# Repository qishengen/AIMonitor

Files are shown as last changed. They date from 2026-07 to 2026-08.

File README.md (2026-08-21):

# AIMonitor

用来展示 AI 状态的桌面小玩具：ESP-12F + SSD1306 128x64 OLED 动画播放器，配像素动画编辑器。支持**串口 + WiFi/TCP 双通路**控制，**浏览器 Web 配网**。

## 目录结构

```
Code/AIMonitor/            ESP8266 固件（FW 1.3.2：通信层/协议层分离 + WiFi/TCP + Web控制面板）
Code/AIMonitor/docs/       需求/设计/协议/开发摘要（DEV_CONTEXT.md 为后续开发入口）
Code/host/                 Python 上位机（protocol/aimonitor/anm_builder/pxa/ai_stream/tcp_test）
Code/host/tests/           回环自测：串口模拟 15/15 + TCP 模拟(TcpSimServer) 6/6
像素编辑器/                单文件像素动画编辑器 + PXA 分享格式（见 PXA格式.md）
scr/                       示例 GIF 素材（clawd-*.gif）
建模/                      3D 打印模型（壳体/后盖/横棍 .stl）
AIMonitor-32/              ESP32 旧原型，勿与 ESP8266 混淆
```

## 快速上手

1. **烧录**：`Code/AIMonitor` 用 Arduino IDE / arduino-cli 编译烧录（Flash Size 选 4M(FS:3M)，波特率 921600）。上电后**默认 AP+STA**（热点 `AIMonitor-xxxx` 常开），待机屏显示 WiFi 模式/名称/密码/TCP 端口。
2. **Web 控制面板**：手机/PC 连热点 `AIMonitor-xxxx`（**热点默认开放无密码**，可在配网表单「AP 热点密码」或 `ap_pass` 命令设置 ≥8 位密码）→ 浏览器开 `192.168.4.1` → 状态卡片（网络/存储/播放器/系统）+ 文件播放/删除 + 待机/主页/重启/恢复出厂/重连WiFi 按钮 + 配网表单（选 WiFi 填密码保存 → 切路由器，STA 失败 15s 自动退回热点）。门户 AP/STA 任何模式均可达。
3. **TCP 控制**：`python Code/host/tcp_test.py aimonitor.local`（或 `python tcp_test.py <设备IP>`）跑协议测试；也可连串口用原协议。
4. **编辑器**：浏览器打开 `像素编辑器/动画编辑器.html`（设备控制需 Chrome/Edge 且 localhost/https 打开，建议 `python -m http.server`）。画动画 → 上传/流式预览到设备。
5. **分享**：导出 `.pxa` 文本格式存 git，任何人可直接预览/导入。

## 协议

JSON 明文 + `\n`，帧数据体二进制或 base64 双模式。命令：ping/status/stop/list/delete/play/show/stream_*/up_*/transmit/wifi/wifi_status/**ap_pass/wifi_reconnect/home/reset/factory**。串口(921600) 与 TCP(:8088) 双通道，Web 控制面板(:80)。**命令应答只回请求来源，异步事件(进度/完成)广播**。详见 `Code/AIMonitor/docs/PROTOCOL.md` 与 `DEV_CONTEXT.md`。

## 要点速记（详见 DEV_CONTEXT.md）

- 帧数据 **LSB 位序**（字节 bit0=行最左），MSB 会左右镜像。
- GIF 编解码的 LZW 码宽时机很易错，改动需回归验证。
- 固件 IRAM 92%（WiFi 代码全进 Flash 没爆）、RAM 73%、Flash 31%，加代码需留意。
- 回包路由：命令应答回源，异步事件广播；带数据体命令同一时刻只允许一个源。

## TODO（原设想）

1. 构造协议，串口/蓝牙/WiFi 到单片机
2. 单片机做手脚：接屏显示、433 遥控，协议控制
3. 设计 skill 给 AI 装接口

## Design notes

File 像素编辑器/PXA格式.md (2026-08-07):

# PXA 像素动画格式 (v1)

面向 git 分享的**纯文本**像素画/像素动画格式：可直接在代码仓库/文本编辑器里预览，diff 友好，解析简单。

## 特性
- 纯文本、UTF-8、每帧是 ASCII 字符画 → **不装任何工具就能看**
- 自描述：尺寸/帧率/循环/名称都在头部
- 版本化（`;PXA v1`），可向后兼容扩展
- 黑白色（`#`=已绘制，`.`=空白），与 AIMonitor 设备一致；预留调色板扩展位

## 文件示例

```
;PXA v1
;W=8 H=4 F=2 FPS=12 LOOP=1
;NAME=heart
;---- FRAME 0 ----
.#....#.
##.##.##
#######
.#######.
;---- FRAME 1 ----
........
..##.##.
.#######.
.#######.
```

## 语法
| 行 | 含义 |
|---|---|
| `;PXA v1` | 魔数 + 版本（首行） |
| `;W=<宽> H=<高> F=<帧数> FPS=<帧率> LOOP=<0|1>` | 尺寸与播放参数（单行，空格分隔 K=V） |
| `;NAME=<名字>` | 可选，动画名 |
| `;---- FRAME <序号> ----` | 帧分隔符 |
| 其他行 | 像素行：**恰好 W 个字符**，`#`=已绘制(黑)，`.`=空白(白)；共 H 行/帧 |

- `;` 开头的行均为元数据/注释，解析器忽略空行。
- 像素行不足 W 字符时按缺省为 `.`；超出截断（宽容解析）。
- 位序：逐像素从左到右，字符 `#` 对应设备显示 LSB 位（bit0=行最左）。

## 与设备/工具链的关系
- `.pxa` ⇄ XBM(LSB) ⇄ `.anm`（设备二进制，固定 128×64，每帧 1024B）可互转。
- 编辑器（`动画编辑器.html`）支持**导入/导出 PXA**。
- Python 工具：`G:\AIMonitor\Code\host\pxa.py`（`to_pxa` / `parse_pxa`）。
- 上传设备前先切到 128×64(设备) 画布再导/存。

## 分享约定
- 文件名建议 `<名字>.pxa`，放入仓库任意目录即可。
- 保持每帧宽高一致、首行魔数准确，其他工具/人即可直接复用。

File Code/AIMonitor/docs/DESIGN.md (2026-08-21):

# AIMonitor 方案设计文档 (DESIGN)

> 版本: v1.0 ｜ 日期: 2026-08-07 ｜ 状态: 已评审定稿
> **v1.2 扩展（FW 1.2.0）**：架构上新增 `net`（WiFi + TCP Server :8088 + `/wifi.cfg`）与 `webcfg`（Web 配网 :80）两模块；协议状态机由 `protocol_feed()` 统一喂入串口/TCP 字节，`send()` 广播到串口 + 所有 TCP 客户端。详见 `DEV_CONTEXT.md` §13。
> **v1.3 扩展（FW 1.3.0）**：通信层/协议层分离 —— `transport`（串口+TCP+Web 统一字节收发/帧组装）与 `protocol`（命令语义）解耦；回包路由改为**命令应答回源 + 异步事件广播**；Web 门户常开并升级为控制面板（`/status`/`/cmd`）；新增 `home`/`reset`/`factory`/`wifi_reconnect` 命令。权威参考以 `PROTOCOL.md` 与 `DEV_CONTEXT.md` 为准。

## 1. 可行性评估
| 环节 | 约束 | 结论 |
|---|---|---|
| 显示刷新 | SSD1306 经 I2C 全屏刷一帧 ~26-35ms(400kHz) | 上限 ~30fps，动画足够 |
| 串口带宽 | 921600 baud ~90KB/s，单帧 1KB | 理论 ~90fps，非瓶颈 |
| 内存 | ESP-12F 堆 ~40-50KB；方案总占用 <6KB | 充裕 |
| Flash | 4MB (固件 1MB + LittleFS 3MB) | 存储量大 |

## 2. 存储容量计算
- 单帧 128x64/8 = **1024B = 1KB**
- 1 秒动画 @24fps = 24KB；@30fps = 30KB

| 项 | 计算 | 结果 |
|---|---|---|
| LittleFS 可用 | 3MB 分区扣开销 | ~2.5MB |
| 可存全屏帧 | 2.5MB / 1KB | ~2500 帧 |
| 一个动画(60帧@24fps≈2.5s) | 60KB + 8B 头 | 可存 ~40 个 |
| 连续播放上限 | 2500帧@24fps | ~100 秒 |
| 固件体积 | 动画不编译进固件 + 精简代码 | ~150-250KB |

## 3. 动画文件格式 `.anm` (LittleFS)
```
偏移   字段
0-3    "ANM0" 魔数(4B)
4      fps (1B)
5-6    frame_count 小端 (2B)
7      保留 (1B)
8..    每帧 1024B 裸 XBM，顺序拼接
```

## 4. 串口协议

### 通用约定
- 每包 = 一行 JSON 文本 (UTF-8)，以 `\n` 结尾
- 带数据体的包：JSON 头换行后紧跟 `size` 字段指定长度的原始字节
- 数据体双编码：默认二进制；`"enc":"b64"` 时数据为 JSON 内嵌 base64 字符串 `data`
- 设备对每条有效命令回 `ack`，失败回 `nack` + 错误码

### 4.1 PC -> ESP8266 命令
| 分类 | 命令 | JSON 示例 | 说明 |
|---|---|---|---|
| 控制 | ping | `{"cmd":"ping"}` | 握手，回版本/FS容量 |
| 控制 | status | `{"cmd":"status"}` | 回当前状态 |
| 控制 | stop | `{"cmd":"stop"}` | 停止播放 |
| 管理 | list | `{"cmd":"list"}` | 列动画名 |
| 管理 | delete | `{"cmd":"delete","name":"x.anm"}` | 删除动画 |
| 管理 | play | `{"cmd":"play","name":"x.anm","fps":24,"loop":1}` | 播放动画 |
| 实时 | show | `{"cmd":"show","seq":5,"size":1024}` + 1024B | 立即直显一帧，无帧率/总数，完全独立 |
| 实时 | stream_start | `{"cmd":"stream_start","fps":24,"loop":1}` | 动画流开始(total 可选) |
| 实时 | frame | `{"cmd":"frame","seq":0,"size":1024}` + 1024B | 流中一帧，设备按 fps 定时播放 |
| 实时 | stream_end | `{"cmd":"stream_end"}` | 无 total 时显式结束 |
| 写入 | up_begin | `{"cmd":"up_begin","name":"demo.anm","size":61448}` | 开始写入，回 ready |
| 写入 | up_chunk | `{"cmd":"up_chunk","off":0,"size":4096}` + 4096B | 分块写，off 支持断点续传 |
| 写入 | up_end | `{"cmd":"up_end","crc":1234567890}` | CRC32 校验落盘 |
| 写入 | transmit | `{"cmd":"transmit","name":"demo.anm","fps":24,"loop":1,"size":61440}` + 整包 | 整动画一次传入，仅保存 |

所有带数据体命令均支持 `"enc":"b64","data":"..."` 变体。

### 4.2 ESP8266 -> PC 回包
| 回包 | JSON | 含义 |
|---|---|---|
| ack | `{"resp":"ack"}` | 成功 |
| nack | `{"resp":"nack","code":n}` | 失败 (1=未知命令 2=参数错 3=文件不存在 4=CRC错 5=存储满) |
| ready | `{"resp":"ready"}` | 上传/流就绪 |
| done | `{"resp":"done"}` | 上传完成/流结束 |
| progress | `{"resp":"progress","seq":30,"fps":24}` | 播放进度 |
| state | `{"resp":"state","state":"play","name":"x.anm","seq":10}` | 状态查询/变更 |
| pong | `{"resp":"pong","fw":"1.3.2","proto":1,"fs_total":2981888,"fs_free":2800000}` | ping 响应 |
| list | `{"resp":"list","anims":["a.anm","b.anm"]}` | list 响应 |

## 5. 系统架构

### 5.1 ESP8266 固件
```
AIMonitor.ino    主循环: 非阻塞轮询串口 + 驱动播放器
json.h/cpp       最小单层 JSON 解析器 + base64 流式解码(4字符→3字节直写缓冲)
protocol.h/cpp   行缓冲(256B) + 命令分发表(CMD串→handler 函数指针)
player.h/cpp     播放状态机(IDLE/PLAY/SHOW/STREAM) + 双缓冲 + millis fps 定时
fs.h/cpp         LittleFS 读写 .anm / 断点续传 / CRC32
```

**内存预算**: U8g2 缓冲 1KB + 流式双缓冲 2KB + 串口环形缓冲 2KB + 行缓冲 256B + LittleFS 开销 ≈ **<6KB**

**播放器状态机**: IDLE / PLAY_ANIM(读FS) / STREAM(fps定时) / SHOW(即时) 四态

### 5.2 Python 上位机
```
protocol.py     JSON 编解码(bin/b64 双模式) + pySerial 封装 + 回包解析
aimonitor.py    高层 API: play/show/stream/transmit/upload/list/delete/status/ping
anm_builder.py  文字(Pillow)/图片/GIF/AI → .anm
ai_stream.py    AI 联动示例: 生成关键帧 → 流式播放
```

## 6. 优化与拓展要点
- 动画数据全部走 LittleFS，固件小巧
- 命令表为 CMD字符串→handler 映射，加指令只追加一行
- JSON 未知字段忽略 → 向后兼容
- base64 流式解码不整行缓存，省 RAM
- 流播放 fps 用 millis() 节流；LittleFS 逐帧顺序读(1KB <1ms)

## 7. 实施步骤
1. **协议层**: json.h/cpp + protocol.h/cpp + CRC，PC 端回环模拟自测
2. **播放器**: 状态机 + play(LittleFS 读 .anm 播放)
3. **实时显示**: show + stream_start/frame/stream_end，双缓冲边收边播
4. **写入保存**: up_begin/chunk/end + transmit + list/delete
5. **Python 工具集**: protocol → aimonitor → anm_builder → ai_stream
6. **实测**: 帧率/丢帧率/断线续传/稳定性

## 8. 验证方案
- PC 回环模拟器(虚拟串口或本地管道)跑通全指令
- 真机: transmit 60帧 → play 循环；show 即时；stream 24fps
- 断线续传: 中途中断后 up_chunk 指定 off 续传，CRC 通过
- Serial Monitor 人工校验 JSON 明文可读性

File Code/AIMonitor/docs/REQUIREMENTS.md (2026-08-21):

# AIMonitor 需求文档 (REQUIREMENTS)

> 版本: v1.0 ｜ 日期: 2026-08-07 ｜ 状态: 已评审定稿
> **v1.2 扩展（FW 1.2.0）**：新增 WiFi（AP/STA/AP+STA）、协议 TCP 通路(:8088)、浏览器 Web 配网(:80)、待机 IP 屏。硬件接线现为 SCL=5/SDA=4。非功能指标已放宽：固件目标 <=330KB（WiFi 栈入 Flash，实测 327KB/1MB），RAM 应用缓冲实测 64%（lwip/HTTP 缓冲入堆）。协议细节以 `PROTOCOL.md` 为准。

## 1. 项目概述
- **项目名**: AIMonitor
- **定位**: ESP8266 (ESP-12F) 驱动的 SSD1306 128x64 OLED 动画播放器
- **目标**: 通过串口接收上位机(Python)指令，按指令播放 LittleFS 中保存的动画，或实时显示上位机下发的帧。上位机集成 AI，可将文字/图片/AI 生成的内容转成动画下发播放。

## 2. 硬件环境
| 项 | 规格 |
|---|---|
| 主控 | ESP-12F (ESP8266EX, 4MB Flash, RAM ~80KB) |
| 显示屏 | SSD1306 128x64, I2C (SCL=2, SDA=0) |
| 驱动库 | U8g2: `U8G2_SSD1306_128X64_NONAME_F_SW_I2C` (全屏缓冲 1024B) |
| 上位机 | Python 3 + pySerial |
| 串口波特率 | 921600 (可配) |

## 3. 功能需求

### FR1 内置动画播放
- 按动画名播放 LittleFS 中已保存的 `.anm` 动画
- 指令可指定 fps(0=用文件头存储值) 与是否循环
- 播放中周期性上报进度

### FR2 实时帧显示 (show)
- 上位机发送一帧 → 设备立即显示一帧
- **无帧率、无总帧数**，节奏完全由上位机控制
- 与任何模式无关，任意时刻可发（播放中/空闲/流中均生效）

### FR3 动画流播放 (stream)
- 上位机连续发送多帧，设备**按 fps 在设备端定时播放**，多帧组合成动画
- `total` 可选：给则收满自动结束；不给则用 `stream_end` 显式结束
- 帧早到排队(暂存1-2帧,超出丢最新帧策略)、晚到延时到点再播
- 不落盘，适合 AI 现场生成的临时动画

### FR4 动画写入保存 (upload / transmit)
- `upload`: 分块写入大动画，支持**断点续传**、逐块确认、整文件 CRC32 校验落盘
- `transmit`: **一次性整动画传入 → 仅保存 LittleFS**，不自动播放
- 保存后重启仍在（LittleFS 持久化），可用 `play` 随时播放
- 同名文件覆盖 = 更新动画

### FR5 动画库管理
- `list`: 列出 LittleFS 中所有 `.anm` 文件
- `delete`: 按名删除动画
- 管理对象均为**动画文件（整动画）**

### FR6 双向状态上报
- 每条有效指令回 `ack`，失败回 `nack` + 错误码
- 握手 `ping` 返回固件/协议版本、FS 容量
- `status` 返回当前播放状态/动画名/帧进度
- 播放进度上报 `progress`

### FR7 协议易扩展
- 协议头为 **JSON 明文文本**，`\n` 分隔，UTF-8
- 帧/块数据体支持双编码：**原始二进制**（默认，省体积）或 **base64 内嵌 JSON**（纯文本调试/传输）
- 未知字段忽略，向后兼容

### FR8 Python 上位机工具集
- `protocol.py`: JSON 编解码(bin/b64 双模式) + 串口封装
- `aimonitor.py`: 高层 API (play/show/stream/transmit/upload/list/delete/status/ping)
- `anm_builder.py`: 文字/图片/AI → .anm 文件
- `ai_stream.py`: AI 联动示例

## 4. 非功能需求
- **固件体积**: 目标 <= 250KB (尽量精简，动画数据不编译进固件)
- **RAM**: 总占用 < 6KB (U8g2 缓冲 1KB + 双缓冲 2KB + 串口环形缓冲 2KB + 行缓冲 256B + LittleFS 开销)
- **帧率**: OLED I2C 全屏刷新上限 ~30fps；串口 921600 下理论 ~90fps，非瓶颈
- **可靠性**: 坏包丢包重同步、上传断线续传、CRC 校验失败不落盘

## 5. 验收标准
1. PC 端回环模拟器跑通全部 11 条指令的收发与 CRC
2. 真机 `transmit` 上传 60 帧动画后 `play` 正常循环播放
3. `show` 逐帧直显即时响应
4. `stream` 24fps 下无明显卡顿，`total` 与 `stream_end` 两种结束方式均正常
5. 上传中途断电/断线，重连后 `up_chunk` 指定 offset 续传成功，CRC 校验通过
6. `list` / `delete` / `ping` / `status` 全部正常

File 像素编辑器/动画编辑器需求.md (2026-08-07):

像素动画编辑器 - 需求规格说明书
1. 项目概述
一个单页 Web 应用，允许用户在可调节尺寸的画布上逐像素绘制，并管理多帧动画。支持导入/导出多种格式，包括图片、GIF 和 C 语言数组，并内置黑白位图压缩及位序配置功能。目标用户为嵌入式开发者和像素画创作者。

2. 运行环境
纯前端实现，单个 HTML 文件（内嵌 CSS 和 JS），无需构建工具或服务器。

支持现代浏览器：Chrome 90+、Firefox 88+、Edge 90+、Safari 14+。

响应式设计，移动端触摸支持。

3. 数据模型
3.1 帧数据结构
frames: Array<{ pixelData: number[][] }>

pixelData 为 gridSize × gridSize 的二维数组，每个元素为 24 位颜色值（0xRRGGBB）。

白色背景定义为 0xFFFFFF，黑色为 0x000000。

3.2 历史记录
每帧独立维护撤销/重做栈：historyStacks: Array<{ undoStack: Array<number[][]>, redoStack: Array<number[][]> }>。

最大栈深度：80 步。

3.3 全局状态
变量	类型	说明
gridSize	number	当前画布尺寸（宽高相等）
cellSize	number	画布显示单元格像素大小（固定 512px 总宽度）
currentFrameIdx	number	当前编辑帧索引
currentColor	number	当前画笔颜色（0xRRGGBB）
showGrid	boolean	是否显示网格
bwMode	boolean	恒为 true（黑白模式，彩色模式已移除）
zoomLevel	number	画布缩放级别 (1~5)
msbFirst	boolean	位图位序：true=MSB（高位对应左像素），false=LSB
refOpacity	number	参考图透明度 (0~1)
fps	number	动画播放帧率 (1~30)
loop	boolean	播放循环
4. UI 布局
整体采用垂直弹性布局，居中显示，最大宽度 900px。

4.1 布局顺序（自上而下）
标题栏：应用名称 + 画布尺寸下拉选择器（16×16 / 32×32 / 64×64 / 64×32 / 128×64(设备)）。

导入栏：导入图片（→帧）、导入 C 数组、设置参考图。

画笔栏（独占一行，内部元素分散对齐）：

颜色预设：黑、白（橡皮擦）。彩色模式已移除，仅黑白。

操作栏：撤销、重做、清空帧、反色、网格开关、选择工具。

画布区域：

缩放控制条（滑块 + 1:1 复位）。

可滚动容器内包含：

参考背景图层（，默认隐藏）。

像素画布（<canvas>，512×512 CSS 尺寸，内部像素渲染）。

参考图透明度控制条（导入后显示）。

帧操作按钮行（独立居中）：添加帧、复制帧、删除帧、上移帧、下移帧。

帧列表行（最大宽度 520px，居中）：

横向滚动缩略图，每个缩略图 56×56px。

当前帧高亮。

播放控制栏（最大宽度 520px，居中）：

播放/暂停按钮、FPS 滑块、循环复选框。

导出栏（居中）：

导出 PNG、JPEG、BMP、GIF 动画。

导出 C 数组（当前帧 / 全部帧，仅黑白字节位图）。

位序切换按钮（MSB / LSB）。

设备控制面板（新增）：串口连接、上传动画、发送当前帧、设备播放/停止、流式预览、状态查询、日志区。

状态栏：坐标、已绘制像素数、当前帧/总帧数、黑白模式、当前位序。

操作提示。

5. 功能需求
5.1 画布与绘制
5.1.1 像素绘制
使用鼠标左键拖拽绘制当前颜色，右键拖拽擦除（变为白色）。

拖动过程中使用 Bresenham 直线算法插值，保证快速移动时线条连续。

触摸屏支持单指绘制。

5.1.2 颜色管理
点击预设颜色块或使用取色器设置当前颜色。

橡皮擦本质是白色。

黑白模式下，非白色预设颜色自动隐藏，取色器强制为黑色。

5.1.3 网格显示
默认显示浅灰色网格线，可通过按钮切换。

5.1.4 画布缩放
通过滑块（1x~5x，步进 0.25）或 Ctrl+滚轮 调节缩放。

缩放仅影响 CSS transform，不改变像素数据。

缩放后画布容器可滚动。

5.2 帧与动画
5.2.1 帧管理
添加帧：在末尾创建空白帧。

复制帧：复制当前帧并插入其后。

删除帧：删除当前帧（至少保留 1 帧）。

移动帧：上移或下移当前帧。

点击缩略图切换当前编辑帧。

5.2.2 动画播放
循环播放：从当前帧开始，按顺序以设定 FPS 播放。

播放时可切换帧，但暂停后保持当前帧。

不循环时播放到最后一帧停止。

5.3 撤销/重做
每帧独立历史栈，深度 80。

操作（绘制、清空帧、反色）前自动保存快照。

快捷键：Ctrl+Z（撤销）、Ctrl+Y（重做）。

5.4 参考背景图
支持导入图片作为半透明参考图层，覆盖整个画布。

透明度滑块实时调节（0%~100%）。

可清除参考图。

参考图不参与任何导出或像素操作。

5.5 黑白模式
固定为黑白模式（彩色模式已移除），所有非白色绘制强制变为黑色。

颜色预设仅黑、白、橡皮擦。

影响 C 数组导入导出：支持字节级 bit 压缩。

图片导入仍接受彩色图，但导入时自动二值化。

5.6 导入
5.6.1 图片导入
支持 JPG、PNG、GIF。

静态图片：进入「导入预览」——等比缩放居中，可拖动移动、滚轮缩放，选择「填充(全局阈值)」「自适应(局部对比，按邻域均值保留内部明暗细节)」或「轮廓(边缘 Sobel)」二值化，应用后写入当前帧。

GIF 动画：内置 LZW 解码 + 逐帧合成（支持部分帧更新、透明、处置方式 0/1/2/3），等比适应缩放生成多帧，阈值二值化；播放用全局 FPS。

5.6.2 C 数组导入
格式识别：

十六进制字节数组（如 0xFF, 0x0F），根据当前位序解析（仅黑白）。

自动提取宏定义 WIDTH、HEIGHT、FRAME_COUNT，若与当前画布不符则提示用户选择是否调整画布尺寸。

导入前清除所有 #define 行，避免宏数字污染像素数据。

三维数组自动拆分为多帧。

5.7 导出
5.7.1 图片导出
PNG / JPEG (0.92 质量) / BMP (24位) 导出当前帧。

BMP 兼容标准格式，从下至上扫描行，4 字节对齐。

5.7.2 GIF 动画导出
将全部帧以当前 FPS 速度编码为 GIF89a 动画（无限循环）。

内置 GIF 编码器（全局调色板，LZW 压缩）。

5.7.3 C 数组导出
当前帧：const unsigned char bitmap[WIDTH * HEIGHT / 8] = { ... };

全部帧：const unsigned char animation[FRAME_COUNT][WIDTH * HEIGHT / 8] = { ... };

每个字节表示 8 个像素（1=黑，0=白）。

位序由 msbFirst 决定：MSB 时字节高位对应左像素，LSB 时低位对应左像素。

文件头部包含 #define WIDTH、#define HEIGHT、#define FRAME_COUNT（多帧时）。

导出为 .h 文件，可直接下载。

5.8 设备联动（AIMonitor）
通过 Web Serial API（Chrome/Edge，需 localhost/https 打开）连接 ESP8266。

内置 AIMonitor JSON 协议客户端：命令编解码（JSON 明文 + 原始二进制数据体），支持 show/frame/up_chunk 等带数据指令的 size 字段。

控制界面按钮：
- 连接/断开 + 波特率选择（默认 921600）。
- 上传动画：构造 .anm（ANM0 头 + fps + 帧数 + 每帧 1024B XBM），走 up_begin/up_chunk/up_end 分块上传，CRC32(zlib) 校验。
- 发送当前帧：show 命令即时在设备直显当前帧。
- 设备播放/停止：play / stop。
- 流式预览：stream_start/frame/stream_end，按编辑器 FPS 实时推流播放全部帧。
- 状态查询：ping/status/list，回显固件版本、FS 容量、动画列表。
- 日志区显示设备回包（ack/nack/progress 等）。

帧映射：任意画布尺寸等比缩放居中到设备 128×64；128×64 画布为 1:1 原生映射。

6. 交互详情
6.1 快捷键
快捷键	功能
Ctrl + Z	撤销
Ctrl + Y	重做
Ctrl + 滚轮	缩放画布
6.2 鼠标/触摸
左键拖拽：绘制

右键拖拽：擦除（或长按触摸）

滚轮 + Ctrl：缩放

6.3 选择/移动模式
进入：工具栏「🔲 选择」切换。

框选：左键按下开始框选，拖拽扩大选区，抬起结束（单击 = 选中 1 格）。

移动：在已选区域内左键按下并拖拽，像素实时跟随光标移动（实时预览），抬起落下。

取消选择：在选区外单击会开始新框选；右键单击可清空当前选择。

7. 技术实现细节
7.1 GIF 编解码
内嵌独立的 GIF 解码器（支持多帧、LZW 解压、透明色）和编码器（全局颜色表生成、LZW 压缩、动画控制）。

无任何外部依赖。

7.2 位图 bit 打包
导出/导入时按行遍历像素，每 8 个像素压入 1 字节。

位序控制：

MSB：byte |= (1 << (7 - bitPos))

LSB：byte |= (1 << bitPos)

最后不足 8 位的部分自动补零。

7.3 渲染性能
画布宽度固定 512px（cellSize = 512 / gridWidth），高度随画布高宽比自适应；128×64 画布为 512×256。

使用 image-rendering: pixelated 保持清晰边缘。

帧缩略图使用离屏 Canvas 绘制，实时更新。

8. 非功能性需求
可维护性：所有代码内嵌于单一 HTML，结构清晰，注释完整。

兼容性：移动端自适应，缩略图尺寸在窄屏自动缩小。

用户体验：操作有 Toast 提示，重要操作有确认对话框。

9. 文件清单
pixel-editor.html：包含完整 CSS、HTML 和 JavaScript（GIF 编解码器 + 主程序）。

版本历史

版本	日期	修改内容
1.0	2026-07-25	初始完整版
1.1	2026-07-25	增加画布缩放、参考图、布局调整、黑白模式、C 数组宏定义
1.2	2026-07-25	增加位序选项 (MSB/LSB)
1.3	2026-07-25	修复 C 数组导入宏污染 bug
1.4	2026-08-07	移除彩色模式（固定黑白）；支持 128×64 设备尺寸；新增 AIMonitor 设备控制面板（Web Serial 连接、上传动画、发送当前帧、设备播放/停止、流式预览、状态查询）
1.5	2026-08-07	新增 PXA 文本格式导入/导出（git 分享/预览，见 PXA格式.md）
1.6	2026-08-07	重构选择/移动：按下拖拽=框选(抬起结束)；选中区内拖拽=像素实时跟随移动；右键取消选择
1.7	2026-08-07	修复 GIF 编解码（导出结构/码宽/LZW 对齐、导入逐帧合成+处置方式）；静态图片导入改为等比+可缩放/移动+填充(阈值)/自适应(局部对比)/轮廓(Sobel)二值化

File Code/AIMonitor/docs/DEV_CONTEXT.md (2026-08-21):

# 开发摘要上下文 (DEV_CONTEXT)

> 供明天(下一会话)直接继续开发，无需重新沟通。版本: v1.5, 2026-08-21

## 1. 一句话总结
ESP-12F + SSD1306 128x64 OLED 串口动画播放器 + **像素动画编辑器** + **PXA 文本分享格式** + **WiFi/TCP 双通路** + **Web 控制面板**。固件 FW 1.3.2 编译通过（IRAM 92% 无爆），Python 回环 15/15 + TCP 回环 6/6。**FW 1.3.0 将通信层(transport)与协议层(protocol)分离**：transport 统一收串口/TCP/Web 字节并组装帧，protocol 只做命令语义；回包**应答回源 + 事件广播**；Web 门户常开（AP/STA/ap+sta 均可达）并升级为控制面板（`/status` 状态快照 + `/cmd` 控制 + 文件播放/删除 + 待机/主页/重启/恢复出厂/重连WiFi 按钮）。**FW 1.3.1 默认 `ap+sta`（AP 常开）+ 热点密码与 STA 解耦；1.3.2 新增 `ap_pass` 命令（设置/清除 AP 热点密码，串口/TCP/Web 三通道统一）。** 剩真机验证（含 TCP/Web 配网/控制面板）。

## 2. 已确定的关键决策
- 主控: **ESP-12F** (ESP8266EX, 4MB Flash)
- 动画存储: **LittleFS 文件系统** (.anm 文件，动画数据不进固件)
- 双向状态上报: **需要**
- 网络（FW 1.2.0 新增）: **WiFi AP/STA/AP+STA** + 协议 **TCP Server :8088** + **Web 配网 :80**（手写 HTTP），mDNS `aimonitor.local`；纯 STA 连不上 15s 自动退 `ap+sta` 保门户；配置存 `/wifi.cfg`
- 待机屏（FW 1.2.0 新增）: IDLE 状态显示 **IP/TCP 端口/客户端数**（`draw_idle_info`），替代原内置方块动画
- 协议: **JSON 明文文本 + `\n` 分隔**，UTF-8，非二进制魔数头
- JSON 解析: **自写最小单层解析器** (不用 ArduinoJson，省 15-25KB Flash)
- **分层（FW 1.3.0 新增）**: 通信层 `transport.cpp`（串口+TCP+Web 字节收发/帧组装）与协议层 `protocol.cpp`（命令语义）分离；数据命令头由 transport 回调 `on_header` 判定
- **回包路由（FW 1.3.0 新增）**: 命令应答**只回请求来源**（串口/TCP 对应客户端/Web HTTP 响应）；异步事件（progress/done）**广播**串口+所有 TCP
- **Web 门户常开（FW 1.3.0 新增）**: `net_apply()` 后 web server 自动重绑（`webcfg_poll` 用 `net_generation()` 检测），AP/STA/ap+sta 任何模式均可达；默认配置仍为 `ap`
- 帧数据体: **双模式** — 默认原始二进制；`"enc":"b64"` 时 base64 内嵌 JSON
- transmit 行为: **仅保存，不自动播放**，用 play 手动播
- stream 播放节奏: **设备端按 fps 定时**
- show 命令: **完全独立**，任意时刻可发，无帧率/无总帧数，上位机控节奏

## 3. 完整命令清单 (PC -> ESP)
```
{"cmd":"ping"}
{"cmd":"status"}
{"cmd":"stop"}
{"cmd":"list"}
{"cmd":"delete","name":"x.anm"}
{"cmd":"play","name":"x.anm","fps":24,"loop":1}
{"cmd":"show","seq":5,"size":1024}               + 1024B / 或 enc:b64
{"cmd":"stream_start","fps":24,"loop":1}          # total 可选
{"cmd":"frame","seq":0,"size":1024}               + 1024B / 或 enc:b64
{"cmd":"stream_end"}
{"cmd":"up_begin","name":"demo.anm","size":61448}
{"cmd":"up_chunk","off":0,"size":4096}            + 4096B / 或 enc:b64
{"cmd":"up_end","crc":1234567890}
{"cmd":"transmit","name":"demo.anm","fps":24,"loop":1,"size":61440} + 整包
{"cmd":"wifi","mode":"ap|sta|ap+sta","ssid":"..","pass":"..","port":8088}   # 可选字段，持久化+延迟~100ms应用
{"cmd":"ap_pass","pass":"..|''"}        # 设置/清除 AP 热点密码（≥8 位 WPA2，空=开放；FW 1.3.2）
{"cmd":"wifi_status"}
{"cmd":"wifi_reconnect"}        # 用已存配置重连（FW 1.3.0）
{"cmd":"home"}                  # 播放内置主页动画 idle_anim（FW 1.3.0）
{"cmd":"reset"}                 # 重启设备，ack 后延迟 300ms 重启（FW 1.3.0）
{"cmd":"factory"}               # 删 /wifi.cfg + 重启回默认 AP（FW 1.3.0）
```

## 4. 回包清单 (ESP -> PC)
```
{"resp":"ack"}   {"resp":"nack","code":1}   {"resp":"ready"}   {"resp":"done"}
{"resp":"progress","seq":30,"fps":24}
{"resp":"state","state":"play","name":"x.anm","seq":10}   # state: idle|play|stream|home
{"resp":"pong","fw":"1.3.0","proto":1,"ip":"192.168.4.1","fs_total":...,"fs_free":...}
{"resp":"wifi","mode":"ap+sta","ssid":"MyWiFi","ip":"192.168.1.50","port":8088,"clients":1,"sta":1}
{"resp":"list","anims":["a.anm","b.anm"]}
```
错误码: 1=未知命令 2=参数错 3=文件不存在 4=CRC错 5=存储满
> 路由（FW 1.3.0）：命令应答只回请求来源；progress/done 等异步事件广播到串口+所有 TCP。

## 5. .anm 文件格式
```
0-3 "ANM0" | 4 fps | 5-6 frame_count(LE) | 7 保留 | 8.. 每帧1024B裸XBM
```

## 6. 目标文件结构 (已完成)
```
AIMonitor.ino      主循环: transport_poll + net_poll + webcfg_poll + player_tick + protocol_tick；待机信息屏 draw_idle_info
version.h          FW_VERSION/PROTO_VERSION/SERIAL_BAUD 统一常量
transport.h/cpp    通信层(新)：串口+TCP+Web 源抽象 + 帧组装状态机(RX_LINE/RX_B64/RX_TAIL/RX_DATA) + 回源/广播 + transport_exec 供 Web 同步执行
json.h/cpp         最小JSON解析 + base64流式解码
protocol.h/cpp     协议层：命令分发 + 数据 sink(player/fs) + 新命令(reset/factory/home/wifi_reconnect) + 应答回源/事件广播；延迟重启/延迟重连(protocol_tick)
status.h/cpp       状态快照(新)：聚合 net/fs/player/system → Web /status 用
player.h/cpp       状态机(IDLE/PLAY/STREAM/HOME) + 双缓冲2KB + millis fps定时 + 待机信息屏回调(idle_info_cb) + home 内置动画
fs.h/cpp           LittleFS .anm 读写/续传/CRC32/list_array
net.h/cpp          WiFi(AP/STA/AP+STA) + TCP Server(:8088) + /wifi.cfg 配置(含 ap_ssid) + mDNS + STA失败15s退ap+sta兜底 + net_client_read/write + net_generation(web重绑)
webcfg.h/cpp       Web 门户(:80) 常开：GET / /scan /cfg /status，POST /save /cmd；控制面板页(状态卡片+文件播放/删除+功能按钮+配网表单)
--- 上位机 (G:\AIMonitor\Code\host) ---
protocol.py        JSON编解码(bin/b64) + 传输抽象(SerialTransport/TcpTransport/Link) + connect_tcp(host,port)
aimonitor.py       高层API play/show/stream/transmit/upload/list/delete/status/ping
anm_builder.py     文字(Pillow)/图片/GIF/AI -> .anm（to_xbm 为 LSB）
pxa.py             PXA 文本格式编解码 (to_pxa/parse_pxa)，与 .anm/XBM 互转
ai_stream.py       AI联动示例(占位生成器已改 LSB)
tcp_test.py        TCP 通路测试 (python tcp_test.py [host] [port] [--sim] [--upload x.anm])，--sim 回环 6/6
--- 测试 (G:\AIMonitor\Code\host\tests) ---
sim_firmware.py    固件行为模拟器 + TcpSimServer(挂本地 TCP 端口模拟固件 server) + wifi/wifi_status/home/reset/factory/wifi_reconnect 命令模拟
test_loopback.py   PC回环自测 15/15 通过 (python test_loopback.py)
--- 像素编辑器 (G:\AIMonitor\像素编辑器) ---
动画编辑器.html    单文件编辑器：黑白像素画/动画 + 设备控制 + PXA + GIF + 导入预览
动画编辑器需求.md  编辑器需求与版本历史
PXA格式.md         PXA 分享格式规格
```
注: 旧的 IMG.h / wait.h / Base.h (ESP32原型) 已删除/移至 AIMonitor-32，不复用。

## 7. 关键参数速查
- 单帧 128x64/8 = 1024B；1秒@24fps = 24KB；LittleFS 可用 ~2.5MB
- 串口 921600；**协议 TCP :8088；Web 配网 :80**；mDNS `aimonitor.local`；显示上限 ~30fps (I2C瓶颈)
- RAM 预算 <6KB；固件目标 <=250KB（已超出到 ~320KB，可后续裁剪）
- **位序（重要）**：设备显示 `u8g2.drawXBMP` 为 **LSB 位序**（字节 bit0=行最左像素）。所有帧数据生成必须用 LSB：
  - 编辑器 `frameToDeviceBytes`（上传/show/流式）
  - `anm_builder.py to_xbm`
  - 内置 `idle_anim.h`（数组生成脚本：`out[y*8+x//8] |= 1 << (x%8)`）
  - 用 MSB 会导致图像左右镜像。

## 8. 实施顺序 (进度)
1. 协议层: json.h/cpp + protocol.h/cpp + PC 回环自测 —— ✅ 完成
2. 播放器: 状态机 + play —— ✅ 完成
3. 实时: show + stream 双缓冲 —— ✅ 完成
4. 写入: upload + transmit + list/delete —— ✅ 完成
5. Python 工具集 —— ✅ 完成
6. WiFi/TCP 通路: net.h/cpp + protocol_feed/广播 + wifi 命令 + TcpTransport/tcp_test —— ✅ 完成
7. Web 配网: webcfg.h/cpp + STA 兜底 + mDNS + 待机 IP 屏 —— ✅ 完成（编译通过，剩真机验证）
8. 真机验证 —— ⏳ 待做（需要硬件在环）

## 9. 已修复的 bug（v1.1 会话）
- **transmit 双头**：上位机 payload 已含 8B .anm 头，固件 `fs_transmit_begin` 又写一次头 → 文件=16B+帧、无法播放。改为 payload 原样落盘（`fs_transmit_begin(name)` 不再写头）。loopback 增加 `parse_anm` 校验回归。
- **fs.cpp g_name 共享冲突**：upload/transmit 与 play 共用同一静态文件名，播放中途上传会串文件。拆分为 `g_up_name` / `g_anim_name`。
- **player.cpp `loop` 变量名**：与 Arduino 保留 `loop()` 冲突，编译报错。改名 `looping`。
- **串口高速丢字节（FW 1.1.0）**：渲染上屏(I2C ~26ms)或写 Flash 阻塞期间，内核 Serial 接收缓冲仅 256B+FIFO128B，1KB+ 帧数据突发会溢出丢字节 → 设备卡在 RX_DATA 永久不回包。修复：`setup()` 里 `Serial.setRxBufferSize(4096)`（必须在 begin 前）；协议环形缓冲 2048→8192；批写 64→256；新增 1s 收包超时（数据不完整即复位回 nack(2)，不再卡死）。
- **编辑器上传/流式**：上传分块 4096→2048、加 ping 握手、失败自动重试一次、nack 直接报真实错误码；流式预览先 `stop` 复位、`frame` 并发保护、progress 日志节流。
- **GIF 导出坏文件（v1.2 会话）**：图像描述符漏本地颜色表标志(写 0x00 又加多余字节)、min code size 硬编码 8、LZW 首个新码从 clear 开始、码宽增长时机错一个、位打包用有符号 `>>` 溢出。已修，PIL 实测 8×8~200×200 精确解码。
- **GIF 导入残缺（v1.2 会话）**：缺逐帧合成，部分帧/透明/处置方式动画只显示局部矩形。已加 `compositeAll()`（处置 0/1/2/3）+ LZW end 码占位，clawd 真机 gif 像素级一致。

## 10. 编译验证（已通过）
```
arduino-cli compile --fqbn esp8266:esp8266:generic:xtal=160,vt=flash,exception=disabled,\
stacksmash=disabled,ssl=all,mmu=3232,non32xfer=fast,FlashMode=dout,FlashFreq=40,eesz=4M3M,\
led=2,ip=lm2f,dbg=Disabled,lvl=None____,wipe=none,baud=921600 "G:\AIMonitor\Code\AIMonitor"
```
- 结果: EXITCODE=0（FW 1.3.2）。RAM 59276/80192(73%)；IRAM 60851/65536(92%)；Flash 330308B(31%)。
- 依赖: esp8266 core 3.1.2 + U8g2 2.36.19（已装）。
- 注意: WiFi 栈代码几乎全进 Flash（Flash +~49KB），IRAM 仅 +436B，没爆 92% 上限；RAM +~15KB（lwip/HTTP 缓冲/扫描），heap 缩水，加代码留意。
- **编译排坑**：本次曾两次 gcc 因临时文件失败（ICE segfault / `error writing to ...\.s`，磁盘充足，疑杀软）。设 `$env:TMP/TEMP` 到干净目录（如 `...\Temp\opencode\cc_tmp`）后正常。

## 11. 开启动画（内置程序化）
- 在 `AIMonitor.ino` `setup()` 中 `u8g2.begin()` 后阻塞播放约 1.5s：收缩状态圈 + "AIMonitor" 品牌字 + 底部进度条（带奔跑方块），结束后清屏进入主循环。
- 纯 u8g2 图元绘制，无文件/无帧缓冲依赖；用 `u8g2_font_6x13_tf` 字体（+~1KB Flash）。
- 期间串口仍能缓存少量命令（如 ping），主循环开始后正常处理；改动该动画只需改 `boot_animation()`。

## 12. 待机屏（IDLE 状态）
- **FW 1.2.0 起：IDLE 显示配网信息屏**（替代方块动画）。`player.cpp` 注册 `idle_info_cb`，`AIMonitor.ino` 的 `draw_idle_info()` 用 u8g2 6x13 画 4 行：标题 `AIMonitor` + `模式 名称`（`ap+sta AIMonitor-xxxx`，AP 开则热点名否则 STA ssid，`net_mode_str`/`net_ap_ssid_str`/`net_ssid_str`）+ `PASS xxx`（空=开放热点，`net_pass_str`）+ `TCP 8088 C:客户端数`。右上角呼吸点每 700ms 闪。**不显示 Web 端口。**
- **FW 1.3.1 起默认模式 `ap+sta`（AP 常开）**：`net_default_cfg` 默认 `ap+sta`，热点恒可用，STA 有 ssid 才连；**AP 热点密码独立**（1.3.2 `ap_pass` 命令可设，空=开放），待机屏 `PASS` 行显示 `ap_pass` 或 `PASS (open)`。
- 方块动画兜底：未注册 idle_info_cb 时仍用 `idle_anim.h`（64x64 帧数组，`idle_render()` 居中合成）。改动待机屏只改 `draw_idle_info()`。
- **FW 1.3.0：新增 `home` 命令播内置主页动画**（`player_play_home`，状态 ST_HOME，循环播放 idle_anim 直至 stop/show/play/stream；`show` 在 home 下先回 idle-hold）。
- 交互不变：`show` 置 `idle_hold=true` 暂停（保持所显帧），`play`/`stream` 结束或 `stop` 时 `idle_resume()` 恢复信息屏。

## 13. WiFi / TCP / Web 控制面板（FW 1.2.0 新增，1.3.0 升级）
- **net.h/cpp**：配置结构 `net_cfg_t`（mode/ssid/pass/ap_ssid/**ap_pass**/port/静态IP），存 `/wifi.cfg`（key=value 文本）。`net_setup()` 读取并 `net_apply()`：`WiFi.mode` 按 `ap|sta|ap+sta`、**AP 名用 `ap_ssid` 否则 `AIMonitor-<chipid>`（1.3.0 修复：不再误用 STA ssid 当热点名）**、STA 支持 DHCP/静态 IP；`WiFiServer(:8088)` + `net_client_write(idx,...)` 单发/`net_broadcast()` 广播（上限 2）。**默认模式 `ap+sta`（1.3.1，AP 常开）**。**AP 热点密码独立（1.3.2 新增 `ap_pass` 命令）**：1.3.1 曾固定开放（`pass` 曾复用为热点密码导致手机"验证身份失败"，已解耦）；现空=开放、≥8 位=WPA2（`WiFi.softAP(ssid, ap_pass? : NULL, 1, 0, 8)`，客户端上限 8）；`net_ap_pass_str()` 供待机屏/状态展示。**改网命令（wifi/ap_pass/wifi_reconnect）统一"先 ack 后延迟 ~100ms 应用"（`g_reapply_at`）**，保证串口/TCP/Web 各通道先收到回包。
- **通信层/协议层分离（FW 1.3.0）**：`transport.cpp` 统一收串口/TCP/Web 字节（同一 8KB ring）并组装帧，回调 `on_line/on_header/on_payload/on_done/on_timeout` 交给 `protocol.cpp`；`transport_exec()` 供 Web 同步执行命令并捕获回包。**回包路由：命令应答回源（`transport_send_line`）、异步事件广播（`transport_broadcast_line`）**。`show/frame/up_chunk/transmit` 同一时刻只允许一个源（单管线，天然限制）。
- **命令（1.3.0 新增）**：`home`（内置主页动画）、`reset`（ack 后延迟 300ms 重启）、`factory`（删 /wifi.cfg + 重启回默认 AP）、`wifi_reconnect`（重读配置延迟 100ms 重连，`protocol_tick` 执行）。`ping` 的 pong 含 `ip`。协议版本 `proto=1`，FW `1.3.0`。
- **webcfg.h/cpp**：手写 HTTP 门户 `:80`（不引 ESP8266WebServer，保 IRAM）。路由 `GET /`(控制面板) `/status`(状态快照) `/scan`(AP列表) `/cfg`(预填) `POST /save` `/cmd`。**`/cmd` 用 `protocol_web_exec`（1.3.1 修复：不经过 transport 帧状态机，独立解析分发，串口/TCP 数据包占用时不再返回 busy/失败）；`WEB_MAX_CLIENTS` 2→4（首页 4 个并行 fetch，防丢连接）**。**门户常开**：`webcfg_poll` 用 `net_generation()` 检测 `net_apply` 后重绑 server，AP/STA/ap+sta 均可达。配置页 JS 用 esprima 校验过；HTTP 解析逻辑有 Python 镜像测试（header_end/content_length/url_decode/分块/中文 SSID）。
- **STA 兜底**：纯 `sta` 15s 连不上 → 运行时自动退 `ap+sta` 保门户（不持久化）；mDNS `aimonitor.local`（STA 联网后可 `http://aimonitor.local`）。
- **待机屏**：IDLE 显示 IP/TCP 端口/客户端数（见 §12）。
- **上位机**：`protocol.py` 加 `TcpTransport`/`connect_tcp(host,port)`，`Link`/`AIMonitor` 零改动；`tcp_test.py` 真机/回环测试（`--sim` 用 `sim_firmware.TcpSimServer`，6/6）。编辑器仍走 Web Serial，未接 TCP/WebSocket（后续可选）。

## 14. 像素编辑器（G:\AIMonitor\像素编辑器\动画编辑器.html）
- 单文件纯前端，无依赖。**纯黑白**（彩色已移除），画布尺寸 16/32/64/64×32/128×64(设备)。
- 设备面板用 **Web Serial API**（Chrome/Edge，需 localhost/https 打开；file:// 下不可用）：连接→上传动画(分块+CRC)、发送当前帧、设备播放/停止、流式预览、状态/删除。
- 帧→设备 128×64 XBM：`frameToDeviceBytes`，**等比缩放居中**（任意画布尺寸），LSB 位序。
- 选择/移动：左键拖拽=框选(抬起结束)，选中区内拖拽=像素实时跟随，右键取消选择。
- 关键校验命令：
  - JS 语法/ID：`python C:\Users\90346\AppData\Local\Temp\opencode\check_js.py`（esprima）
  - 帧/CRC/.anm/PXA 逻辑：`check_logic.py` / `check_chain.py` / `check_pxa.py`
  - GIF 编码 vs PIL：`check_final.py`；解码 vs 真实 gif：`check_content.py`
- 注意：仓库里 `动画编辑器 - 副本.html` 是旧备份，别改错文件。

## 15. PXA 分享格式（git 友好）
- 纯文本，`;` 元数据行 + `#`=黑 `.`=白 像素行；`;PXA v1` 魔数、`;W= H= F= FPS= LOOP=`、`;NAME=`、`;---- FRAME N ----` 分隔。
- 任意尺寸，编辑器可导入/导出；Python 端 `host/pxa.py`；与 .anm 互转仅限 128×64。
- 规格见 `像素编辑器\PXA格式.md`。

## 16. GIF 编解码要点（容易再踩坑，改动需回归验证）
- **码宽增长时机**（最易错）：编码器用 `nextCode >= (1<<codeSize)+1`（比字典计数晚一个），与标准解码器"首个新码由第 2 码经 KwKwK 构建"对齐。改回 `>= (1<<codeSize)` 会导出坏文件。
- LZW 首个新码 = `clear+2`；位打包必须用无符号 `>>>`（有符号 `>>` 溢出）。
- 调色板补齐 2 的幂；min code size 与 LZW 一致；图像描述符 packed 含本地颜色表标志 `0x80|(bits-1)`。
- 解码端 `compositeAll()` 逐帧合成（部分帧/透明/处置 0/1/2/3），先合成再缩放。
- 回归：`check_final.py`（编码 vs PIL）、`check_content.py`（解码 vs 真实 gif）。

## 17. 导入图片设计（静态图片）
- 交互式「导入预览」：等比缩放居中 → 拖动移动 + 滚轮缩放(光标为中心) + ↔ 适应复位 → 应用写当前帧/取消。
- 二值化三种模式：
  - 填充(全局阈值)：`gray < T` 黑。
  - **自适应(局部对比)**：`gray < 局部均值 - C`（邻域约 1/6 画布），按局部明暗保留内部细节（照片/渐变适用）。
  - 轮廓(边缘 Sobel)：梯度幅值 > T 黑，出线稿。
- 空白区按白处理；GIF 导入走等比适应 + 阈值。

## 18. 下一步(推荐起点)
1. 真机验证（优先级）：
   - 串口/TCP 双通路：`tcp_test.py aimonitor.local`（或 AP 下 `tcp_test.py 192.168.4.1`）跑 ping/wifi_status/transmit/play/show/stream。
   - **Web 控制面板（1.3.0 新）**：连热点 `AIMonitor-xxxx` → `192.168.4.1` → 状态卡片(网络/存储/播放器/系统)自动刷新、文件列表播放/删除、按钮(待机/主页动画/重连WiFi/重启/恢复出厂)；配网表单保存后设备切 STA → `aimonitor.local` 或路由 IP 再验证；纯 sta 断网 15s 验证退 ap+sta。
   - 原有项：`transmit` 60帧 → `play` 循环；`show` 即时；`stream` 24fps 不卡；断线续传 + CRC。
2. 真机串口 921600，接线 SCL=5/SDA=4（当前 .ino 已配 ESP8266；AIMonitor-32 是旧 ESP32 原型，别混淆）。
3. 上传 60 帧素材：编辑器画 → 上传；或 `scr/` gif：`anm_builder.frames_from_gif` → `mon.transmit`。
4. 固件资源：IRAM 92%（WiFi 全进 Flash 没爆，再加代码小心）；RAM 73%（transport/status/webcfg/Web槽×4 新增）；Flash 31%。

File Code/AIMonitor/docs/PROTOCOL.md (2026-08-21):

# AIMonitor 串口协议完整规范 (PROTOCOL)

> 版本: v1.2 ｜ 日期: 2026-08-21 ｜ 实现: `Code/AIMonitor/protocol.cpp`（协议层）+ `Code/AIMonitor/transport.cpp`（通信层）+ `Code/host/protocol.py`（上位机端）
> v1.2 变更：通信层/协议层分层重构（transport.cpp 管字节收发，protocol.cpp 管命令语义）；回包路由改为**命令应答回源 + 异步事件广播**；新增 `home`/`reset`/`factory`/`wifi_reconnect` 命令；Web 门户升级为控制面板（`/status` `/cmd`）；FW 升至 1.3.0。
> v1.1 变更：新增 WiFi TCP 通路（:8088）、Web 配网（:80）、`wifi`/`wifi_status` 命令、`ping` 回包增加 `ip` 字段；FW 升至 1.2.0。

本文档为协议权威参考。数据来源：`protocol.cpp` 实际实现、`DESIGN.md`、`DEV_CONTEXT.md`。

---

## 1. 概述

| 项 | 值 |
|---|---|
| 传输介质 | 串口 UART（默认 921600 baud，可配）+ **TCP Server（默认 :8088）**，双通道共用同一协议状态机 |
| 编码 | UTF-8 文本，一包一行 |
| 包分隔 | `\n`（LF） |
| 数据体 | 原始二进制（默认）或 base64 内嵌（`"enc":"b64"`）双模式 |
| JSON 能力 | 单层解析，value 仅支持字符串/整数，未知字段忽略 |
| 协议版本 | `proto = 1`，固件 `fw = "1.3.2"` |
| Web 控制面板 | HTTP :80（`GET /` 面板、`/status` 快照、`/cfg`、`/scan`；`POST /save`、`/cmd`），非协议端口，见 `webcfg.cpp` |

接收端资源：行缓冲 256B、串口环形缓冲 8192B、数据批写 256B/批、收包不完整超时 1s（超时复位并回 `nack(2)`，防止卡死）。

**分层架构（FW 1.3.0）**：`transport.cpp`（通信层）统一收串口/TCP/Web 字节并组装帧，`protocol.cpp`（协议层）只做命令语义。回包路由：
- **命令应答**（ack/nack/ready/done/state/list/pong/wifi）→ **只回请求来源**（串口命令回串口、TCP 命令回对应客户端、Web 操作回 HTTP 响应体）
- **异步事件**（progress/done 播放上报）→ **广播**到串口 + 所有 TCP 客户端

---

## 2. 报文结构（三种形态）

### 2.1 普通命令（无数据体）

```
{"cmd":"ping","name":"x.anm","fps":24,"loop":1}\n
```

### 2.2 带数据体 — 原始二进制（默认，省体积）

JSON 头一行（含 `"size"` 声明长度），换行后紧跟 `size` 字节原始数据：

```
{"cmd":"show","seq":5,"size":1024}\n<1024 bytes raw XBM>
{"cmd":"up_chunk","off":0,"size":4096}\n<4096 bytes raw>
```

### 2.3 带数据体 — base64 内嵌（纯文本调试/传输）

数据以 base64 字符串放在 JSON 的 `"data"` 字段内，无需换行：

```
{"cmd":"show","seq":5,"size":1024,"enc":"b64","data":"AQID...=="}\n
```

> 固件端按 `"data":"` 标记流式切换到 base64 解码（`protocol.cpp:307`）。`enc` 字段本身并不参与判断，只要数据内嵌在 `"data"` 中即走 b64 路径。

---

## 3. PC → 设备 命令表

> 约定：**成功回包** 一列中的 `ack` 用 `{"resp":"ack"}` 表示；`state` 为 `{"resp":"state",...}`；`ready` 为 `{"resp":"ready",...}`。参数错一律回 `nack(2)`。

### 3.1 控制类

#### ping — 握手/探测

```json
{"cmd":"ping"}
```

- 参数：无
- 成功回包：`pong`（含固件版本/协议版本/FS 总容量/空闲）
- 失败回包：无

**demo**
```python
from protocol import Link, SerialTransport
import serial
mon_link = Link(SerialTransport(serial.Serial("COM5", 921600, timeout=0)))
print(mon_link.request({"cmd":"ping"}, expect=("pong",)))
# {"resp":"pong","fw":"1.3.2","proto":1,"ip":"192.168.4.1","fs_total":2981888,"fs_free":2800000}
```

---

#### status — 查询当前状态

```json
{"cmd":"status"}
```

- 参数：无
- 成功回包：`state`（state/name/seq）
- 失败回包：无

**demo**
```python
resp = mon_link.request({"cmd":"status"}, expect=("state",))
# {"resp":"state","state":"play","name":"demo.anm","seq":10}
```

---

#### stop — 停止播放

```json
{"cmd":"stop"}
```

- 参数：无
- 成功回包：`state`（固定 `state:"idle",name:"",seq:0`）
- 失败回包：无

**demo**
```python
mon_link.request({"cmd":"stop"}, expect=("state","ack"))
# {"resp":"state","state":"idle","name":"","seq":0}
```

---

#### home — 播放内置主页动画

```json
{"cmd":"home"}
```

- 参数：无
- 成功回包：`state`（`state:"home"`，seq:0）
- 失败回包：无
- 特性：播放内置 64x64 主页动画（`idle_anim.h`，循环），直到 `stop`/`show`/`play`/`stream` 打断；Web 控制面板「主页动画」按钮即发此命令

**demo**
```python
mon_link.request({"cmd":"home"}, expect=("state",))
# {"resp":"state","state":"home","name":"","seq":0}
```

---

### 3.2 管理类

#### list — 列出所有 .anm 动画

```json
{"cmd":"list"}
```

- 参数：无
- 成功回包：`list`（`anims` 数组）
- 失败回包：`nack(2)`（FS 枚举失败）

**demo**
```python
resp = mon_link.request({"cmd":"list"}, expect=("list",))
# {"resp":"list","anims":["demo.anm","boot.anm"]}
```

---

#### delete — 按名删除动画

```json
{"cmd":"delete","name":"demo.anm"}
```

- 参数：`name`（必填，文件名含 `.anm`）
- 成功回包：`ack`
- 失败回包：`nack(3)` 文件不存在；`nack(2)` 缺 name

**demo**
```python
resp = mon_link.request({"cmd":"delete","name":"demo.anm"})
# {"resp":"ack"}
```

---

#### play — 播放 LittleFS 中的动画

```json
{"cmd":"play","name":"demo.anm","fps":24,"loop":1}
```

- 参数：`name` 必填；`fps` 可选（0=用 .anm 文件头存储值）；`loop` 可选（非 0 循环）
- 成功回包：`state`（`state:"play"`，seq 从 0 开始）
- 失败回包：`nack(3)` 文件不存在；`nack(2)` 缺 name
- 其他：播放中周期上报 `progress`

**demo**
```python
mon_link.request(
    {"cmd":"play","name":"demo.anm","fps":24,"loop":1},
    expect=("state","ack"),
)
# {"resp":"state","state":"play","name":"demo.anm","seq":0}
```

---

### 3.3 实时显示类

#### show — 立即直显一帧

```json
{"cmd":"show","seq":5,"size":1024}\n<1024B 原始 XBM>
```

- 参数：`seq` 可选（帧序号）；`size` 必填且必须等于 `1024`
- 数据体：1 帧 128x64 XBM（1024B，LSB 位序）
- 成功回包：`ack`
- 失败回包：`nack(2)` size≠1024 或数据不完整
- 特性：完全独立，任意时刻可发（播放中/空闲/流中均生效），无帧率/总数，节奏由上位机控制

**demo**
```python
frame = bytes(1024)                     # 一帧全黑 XBM
mon_link.request({"cmd":"show","seq":5}, payload=frame, enc="bin")
# 等价 b64：mon_link.request({"cmd":"show","seq":5,"enc":"b64"},
#                           payload=frame, enc="b64")
# {"resp":"ack"}
```

---

#### stream_start — 动画流开始

```json
{"cmd":"stream_start","fps":24,"loop":1}
{"cmd":"stream_start","fps":24,"loop":0,"total":60}
```

- 参数：`fps` 可选（默认 24，固件夹到 1~60）；`loop` 可选（非 0 循环）；`total` 可选（给则收满自动结束，不给用 `stream_end` 显式结束）
- 成功回包：`state`（`state:"stream"`）
- 失败回包：无
- 特性：设备端按 fps 定时播放，帧早到排队（暂存 1-2 帧，超丢最新），晚到延时到点再播；不落盘

**demo**
```python
resp = mon_link.request(
    {"cmd":"stream_start","fps":24,"loop":1},
    expect=("state","ready"),
)
# {"resp":"state","state":"stream","name":"","seq":0}
```

---

#### frame — 流中发送一帧

```json
{"cmd":"frame","seq":0,"size":1024}\n<1024B 原始 XBM>
```

- 参数：`seq` 可选；`size` 必填且必须等于 `1024`
- 数据体：1 帧 XBM（1024B，LSB 位序）
- 成功回包：`ack`
- 失败回包：`nack(2)` size≠1024 或数据不完整

**demo**
```python
for i in range(60):
    frame = bytes(1024)                # 实际应替换为第 i 帧数据
    mon_link.request({"cmd":"frame","seq":i}, payload=frame)
    # {"resp":"ack"}
```

---

#### stream_end — 流显式结束

```json
{"cmd":"stream_end"}
```

- 参数：无
- 成功回包：`done`
- 失败回包：无
- 特性：仅当 stream_start 未给 `total` 时需要

**demo**
```python
resp = mon_link.request({"cmd":"stream_end"}, expect=("done","ack"))
# {"resp":"done"}
```

---

### 3.4 写入保存类

#### up_begin — 分块上传开始（断点续传）

```json
{"cmd":"up_begin","name":"demo.anm","size":61448}
```

- 参数：`name` 必填；`size` 必填，须 `>= 8` 且 `(size-8) % 1024 == 0`
- 成功回包：`ready`（含 `off` = 当前磁盘已写字节数，续传起点）
- 失败回包：`nack(2)` 参数错；`nack(5)` 存储满
- 特性：同名同尺寸保留原文件支持续传，否则重建

**demo**
```python
data = open("demo.anm","rb").read()   # 完整 .anm（含 8B 头）
resp = mon_link.request(
    {"cmd":"up_begin","name":"demo.anm","size":len(data)},
    expect=("ready",),
)
off = resp.get("off", 0)               # 断线后续传起点
# {"resp":"ready","off":0}
```

---

#### up_chunk — 分块写入数据

```json
{"cmd":"up_chunk","off":0,"size":4096}\n<4096B 原始>
```

- 参数：`off` 必填（>=0，写入偏移）；`size` 必填
- 数据体：任意字节数（<= 4096 建议）
- 成功回包：`ack`
- 失败回包：`nack(2)` 未先 up_begin、off 非法、或数据不完整
- 特性：off 支持断点续传；每块回 ack 后上位机发下一块

**demo**
```python
chunk = 4096
for off in range(off, len(data), chunk):
    piece = data[off:off+chunk]
    mon_link.request({"cmd":"up_chunk","off":off}, payload=piece)
    # {"resp":"ack"}
```

---

#### up_end — 上传结束 + CRC 校验落盘

```json
{"cmd":"up_end","crc":1234567890}
```

- 参数：`crc` 必填（整文件 CRC32，无符号 32 位）
- 成功回包：`done`
- 失败回包：`nack(4)` CRC 校验失败（自动删除坏文件，不落盘）；`nack(2)` 缺 crc 或未 up_begin
- 特性：CRC 校验通过才正式落盘

**demo**
```python
import zlib
crc = zlib.crc32(data) & 0xFFFFFFFF
resp = mon_link.request({"cmd":"up_end","crc":crc}, expect=("done",))
# {"resp":"done"}
```

---

#### transmit — 整动画一次传入，仅保存

```json
{"cmd":"transmit","name":"demo.anm","fps":24,"loop":1,"size":61440}\n<整 .anm 文件>
```

- 参数：`name` 必填；`size` 必填，须 `>= 8` 且 `(size-8) % 1024 == 0`；`fps`/`loop` 可选（存元数据，但播放用 play 命令指定或文件头 fps）
- 数据体：完整 `.anm` 文件（含 8B 头），原样落盘，不自动播放
- 成功回包：`done`
- 失败回包：`nack(2)` 参数错；`nack(5)` 存储满
- 特性：`fps`/`loop` 仅作记录，不参与播放控制

**demo**
```python
from anm_builder import build_anm
data = build_anm(frames, fps=24)       # frames: [1024B XBM,...]，LSB 位序
mon_link.request(
    {"cmd":"transmit","name":"demo.anm","fps":24,"loop":1,"size":len(data)},
    payload=data, expect=("done",),
)
# {"resp":"done"}
```

---

### 3.5 网络配置类

#### wifi — 配置/切换 WiFi 模式（持久化 + 即时生效）

```json
{"cmd":"wifi","mode":"sta","ssid":"MyWiFi","pass":"12345678"}
{"cmd":"wifi","mode":"ap+sta","port":9000}
```

- 参数：`mode`(ap|sta|ap+sta)、`ssid`、`pass`、`port`(1..65535) 均可选，未下发字段保持原配置
- 成功回包：`ack`（**先回包后应用**：应用配置会短暂断开当前 TCP 连接）
- 失败回包：`nack(2)` 参数错
- 特性：写入 LittleFS `/wifi.cfg` 持久化并即时生效；重启仍生效。`ap` 且 ssid 留空时热点名自动为 `AIMonitor-<chipid>`；STA 可配静态 IP（`/wifi.cfg` 手改 ip/gw/mask）。**AP 热点密码独立**（空=开放，≥8 位=WPA2，见 `ap_pass` 命令）；`pass` 仅用于 STA 连路由器，不作用于热点。客户端上限 8（`WiFi.softAP(...,max_connection=8)`）。**回包后延迟 ~100ms 应用**（`g_reapply_at`，串口/TCP/Web 各通道先收到 ack）。
- 同功能也可用 Web 配网完成：浏览器打开 `http://<设备IP>`（:80）

**demo**
```python
mon_link.request({"cmd":"wifi","mode":"sta","ssid":"MyWiFi","pass":"12345678"})
# {"resp":"ack"}
```

---

#### ap_pass — 设置/清除 AP 热点密码

```json
{"cmd":"ap_pass","pass":"12345678"}   # 设置（≥8 位，WPA2）
{"cmd":"ap_pass","pass":""}            # 清除（热点开放）
```

- 参数：`pass` 必填；空字符串=开放热点，≥8 位=启用 WPA2，长度 1~7 返回 `nack(2)`
- 成功回包：`ack`（先回包后延迟 ~100ms 应用）
- 失败回包：`nack(2)` 缺 pass 或长度 1~7
- 特性：持久化到 `/wifi.cfg` 并即时生效；与 STA 密码独立（STA 密码不作用于热点）；**串口/TCP/Web 三通道统一走协议分发**（Web 控制面板配网表单「AP 热点密码」字段同功能）；待机屏 `PASS` 行实时显示。

**demo**
```python
mon_link.request({"cmd":"ap_pass","pass":"12345678"})
# {"resp":"ack"}
```

---

#### wifi_status — 查询当前 WiFi 状态

```json
{"cmd":"wifi_status"}
```

- 参数：无
- 成功回包：`{"resp":"wifi","mode":"sta","ssid":"MyWiFi","ip":"192.168.1.50","port":8088,"clients":1,"sta":1}`
- 失败回包：无
- 字段：`mode` 当前模式、`ssid`（ap 模式留空=自动热点名）、`ip` 设备 IP、`port` TCP 端口、`clients` 已连接 TCP 客户端数、`sta` 是否已连上路由器

**demo**
```python
resp = mon_link.request({"cmd":"wifi_status"}, expect=("wifi",))
# {"resp":"wifi","mode":"ap+sta","ssid":"MyWiFi","ip":"192.168.1.50","port":8088,"clients":1,"sta":1}
```

---

### 3.6 设备管理类

#### wifi_reconnect — 用已存配置重新连接 WiFi

```json
{"cmd":"wifi_reconnect"}
```

- 参数：无
- 成功回包：`ack`（回包后延迟 ~100ms 再应用，保证 Web 请求方收到响应）
- 失败回包：无
- 特性：等价于重读 `/wifi.cfg` 并 `net_apply()`；Web 控制面板「重连WiFi」按钮即发此命令

**demo**
```python
mon_link.request({"cmd":"wifi_reconnect"})
# {"resp":"ack"}
```

---

#### reset — 重启设备

```json
{"cmd":"reset"}
```

- 参数：无
- 成功回包：`ack`（回包后延迟 ~300ms 再重启，保证响应发出）
- 失败回包：无

**demo**
```python
mon_link.request({"cmd":"reset"})
# {"resp":"ack"}  之后设备重启
```

---

#### factory — 恢复出厂（清配网 + 重启）

```json
{"cmd":"factory"}
```

- 参数：无
- 成功回包：`ack`（回包后延迟 ~300ms 再重启）
- 失败回包：无
- 特性：删除 `/wifi.cfg` 并重启，回到默认 AP 热点模式（`AIMonitor-<chipid>`，:80 配网门户可用）

**demo**
```python
mon_link.request({"cmd":"factory"})
# {"resp":"ack"}  之后设备重启回默认 AP
```

---

## 4. 设备 → PC 回包表

| 回包 | JSON | 含义 |
|---|---|---|
| ack | `{"resp":"ack"}` | 成功 |
| nack | `{"resp":"nack","code":n}` | 失败（见 §5） |
| ready | `{"resp":"ready","off":4096}` | 上传/流就绪，off 为续传起点 |
| done | `{"resp":"done"}` | 上传完成/流结束 |
| progress | `{"resp":"progress","seq":30,"fps":24}` | 播放进度（播放中周期上报，**广播**） |
| state | `{"resp":"state","state":"play","name":"x.anm","seq":10}` | 状态查询/变更结果（state 可为 idle/play/stream/home） |
| pong | `{"resp":"pong","fw":"1.3.2","proto":1,"ip":"192.168.4.1","fs_total":2981888,"fs_free":2800000}` | ping 响应 |
| wifi | `{"resp":"wifi","mode":"ap+sta","ssid":"MyWiFi","ip":"192.168.1.50","port":8088,"clients":1,"sta":1}` | wifi_status 响应 |
| list | `{"resp":"list","anims":["a.anm","b.anm"]}` | list 响应 |

> 回包同样是 `\n` 结尾的一行 JSON。上位机在等待某期望回包期间会**忽略** `progress`/`state` 等非期望回包（`protocol.py Link.request`）。

---

## 5. 错误码

| code | 含义 |
|---|---|
| 1 | 未知命令 |
| 2 | 参数错 / 数据不完整 |
| 3 | 文件不存在 |
| 4 | CRC 校验失败（坏文件不落盘） |
| 5 | 存储满 |

---

## 6. .anm 文件格式（LittleFS 存储）

```
偏移    字段
0-3     "ANM0" 魔数 (4B)
4       fps (1B)
5-6     frame_count 小端 (2B)
7       保留 (1B)
8..     每帧 1024B 裸 XBM，顺序拼接
```

- 128x64 单帧 = 128*64/8 = **1024B**
- 1 秒动画 @24fps = 24KB；LittleFS 可用约 2.5MB
- 帧 XBM 为 **LSB 位序**（字节 bit0 = 行最左像素），MSB 会左右镜像

---

## 7. 约束与注意事项

1. **LSB 位序**：所有帧数据（编辑器 `frameToDeviceBytes`、`anm_builder.to_xbm`、内置 `idle_anim.h`）必须是 LSB，否则镜像。
2. **JSON 单层解析**：value 只支持字符串/整数；命令参数中不要出现嵌套对象/数组（除 `list` 回包由固件端自行构造）。
3. **数据完整性**：带数据体命令若收到字节数与 `size` 不符，回 `nack(2)`；1s 无活动则复位状态机（防卡死）。
4. **show/frame 固定 1024B**：`size` 必须为 1024，否则 `nack(2)`。
5. **up_begin/transmit 尺寸约束**：`size >= 8` 且 `(size-8) % 1024 == 0`。
6. **stream 结束方式**：给 `total` 则收满自动结束；否则必须发 `stream_end`。
7. **transmit 不自动播放**：保存后需手动 `play`。
8. **上位机实现速查**：`Code/host/protocol.py`（`encode_packet`/`Link.request`）、`Code/host/aimonitor.py`（高层 API 已封装全部命令）。
9. **TCP 通路（FW 1.2.0）**：协议 TCP Server 默认 `:8088`；`protocol.py` 提供 `TcpTransport`/`connect_tcp(host, port)`，`Link`/`AIMonitor` 无需改动。**FW 1.3.0 起回包路由**：命令应答只回请求来源，异步事件（progress/done）广播到串口 + 所有 TCP 客户端。
10. **单数据流限制**：串口与 TCP 共享同一协议状态机，`show/frame/up_chunk/transmit` 带数据体命令同一时刻只允许一个源（双源并发会串包）。Web `:80` 走独立通道（`transport_exec` 同步执行），不受影响。
11. **Web 控制面板（FW 1.3.0）**：门户在 AP/STA/ap+sta 任何模式均可达；`GET /status` 返回聚合状态快照（网络/存储/播放器/系统），`POST /cmd` 接受 JSON 命令（body 即命令对象），响应体为回包 JSON。
12. **安全**：TCP 无鉴权即可删/传文件，仅限局域网玩具用途。

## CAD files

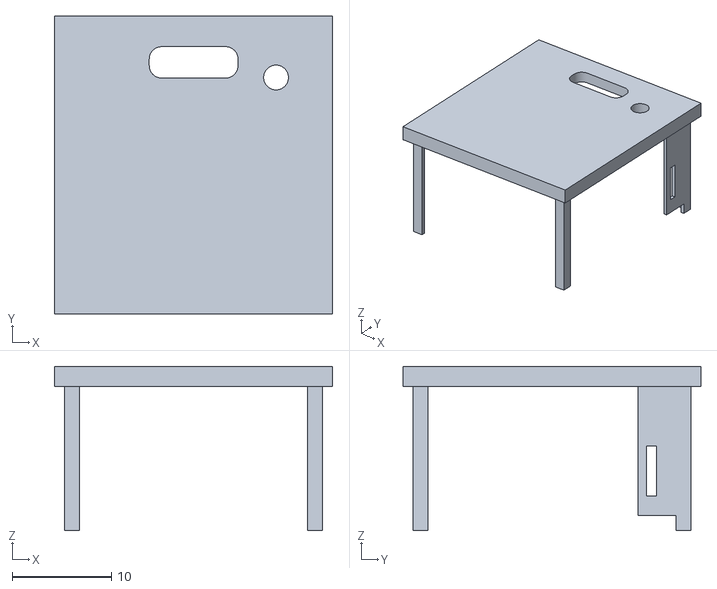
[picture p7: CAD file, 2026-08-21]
建模/后盖.stl
28.0 x 30.0 x 16.5

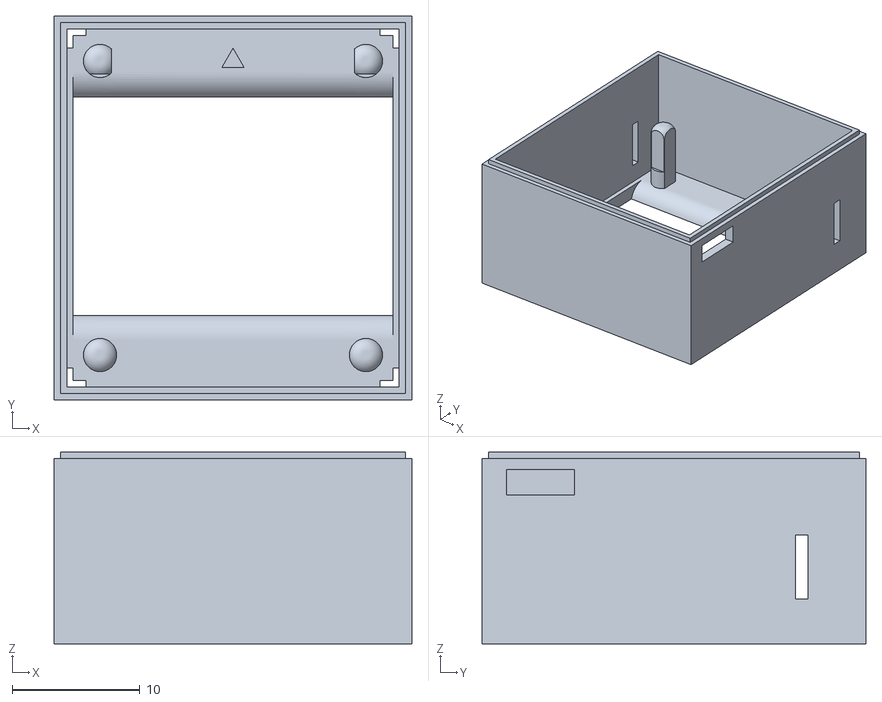
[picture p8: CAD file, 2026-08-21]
建模/壳体.stl
28.0 x 30.0 x 15.0

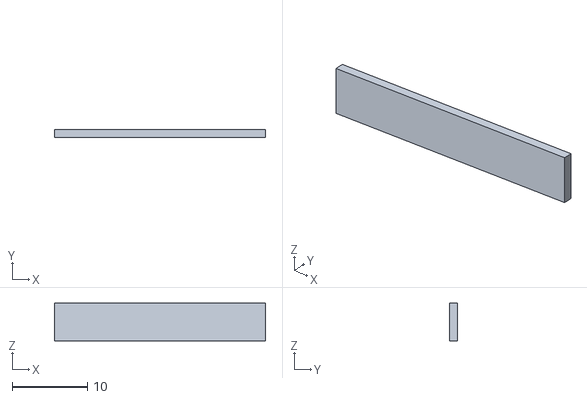
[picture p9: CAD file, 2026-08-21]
建模/横棍.stl
28.0 x 1.00 x 5.00

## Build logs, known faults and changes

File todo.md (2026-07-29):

1. 构造一个协议，串口/蓝牙/wifi to 单片机
2. 把单片机当作手脚，可以接屏幕显示，接433遥控，通过协议控制
3. 设计skill 给ai 装上接口

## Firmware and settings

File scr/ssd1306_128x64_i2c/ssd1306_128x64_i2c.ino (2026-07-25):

/**************************************************************************
 This is an example for our Monochrome OLEDs based on SSD1306 drivers

 Pick one up today in the adafruit shop!
 ------> http://www.adafruit.com/category/63_98

 This example is for a 128x64 pixel display using I2C to communicate
 3 pins are required to interface (two I2C and one reset).

 Adafruit invests time and resources providing this open
 source code, please support Adafruit and open-source
 hardware by purchasing products from Adafruit!

 Written by Limor Fried/Ladyada for Adafruit Industries,
 with contributions from the open source community.
 BSD license, check license.txt for more information
 All text above, and the splash screen below must be
 included in any redistribution.
 **************************************************************************/

#include <SPI.h>
#include <Wire.h>
#include <Adafruit_GFX.h>
#include <Adafruit_SSD1306.h>

#define SCREEN_WIDTH 128 // OLED display width, in pixels
#define SCREEN_HEIGHT 64 // OLED display height, in pixels

// Declaration for an SSD1306 display connected to I2C (SDA, SCL pins)
// The pins for I2C are defined by the Wire-library. 
// On an arduino UNO:       A4(SDA), A5(SCL)
// On an arduino MEGA 2560: 20(SDA), 21(SCL)
// On an arduino LEONARDO:   2(SDA),  3(SCL), ...
#define OLED_RESET     -1 // Reset pin # (or -1 if sharing Arduino reset pin)
#define SCREEN_ADDRESS 0x3C ///< See datasheet for Address; 0x3D for 128x64, 0x3C for 128x32
Adafruit_SSD1306 display(SCREEN_WIDTH, SCREEN_HEIGHT, &Wire, OLED_RESET);

#define NUMFLAKES     10 // Number of snowflakes in the animation example

#define LOGO_HEIGHT   16
#define LOGO_WIDTH    16
static const unsigned char PROGMEM logo_bmp[] =
{ 0b00000000, 0b11000000,
  0b00000001, 0b11000000,
  0b00000001, 0b11000000,
  0b00000011, 0b11100000,
  0b11110011, 0b11100000,
  0b11111110, 0b11111000,
  0b01111110, 0b11111111,
  0b00110011, 0b10011111,
  0b00011111, 0b11111100,
  0b00001101, 0b01110000,
  0b00011011, 0b10100000,
  0b00111111, 0b11100000,
  0b00111111, 0b11110000,
  0b01111100, 0b11110000,
  0b01110000, 0b01110000,
  0b00000000, 0b00110000 };

void setup() {
  // Wire.setPins(0,2);
  Wire.pins(0,2);
  Serial.begin(115200);

  // Wait for display
  delay(500);

  // SSD1306_SWITCHCAPVCC = generate display voltage from 3.3V internally
  if(!display.begin(SSD1306_SWITCHCAPVCC, SCREEN_ADDRESS)) {
    Serial.println(F("SSD1306 allocation failed"));
    for(;;); // Don't proceed, loop forever
  }

  // Show initial display buffer contents on the screen --
  // the library initializes this with an Adafruit splash screen.
  display.display();
  delay(2000); // Pause for 2 seconds

  // Clear the buffer
  display.clearDisplay();

  // Draw a single pixel in white
  display.drawPixel(10, 10, SSD1306_WHITE);

  // Show the display buffer on the screen. You MUST call display() after
  // drawing commands to make them visible on screen!
  display.display();
  delay(2000);
  // display.display() is NOT necessary after every single drawing command,
  // unless that's what you want...rather, you can batch up a bunch of
  // drawing operations and then update the screen all at once by calling
  // display.display(). These examples demonstrate both approaches...

  testdrawline();      // Draw many lines

  testdrawrect();      // Draw rectangles (outlines)

  testfillrect();      // Draw rectangles (filled)

  testdrawcircle();    // Draw circles (outlines)

  testfillcircle();    // Draw circles (filled)

  testdrawroundrect(); // Draw rounded rectangles (outlines)

  testfillroundrect(); // Draw rounded rectangles (filled)

  testdrawtriangle();  // Draw triangles (outlines)

  testfilltriangle();  // Draw triangles (filled)

  testdrawchar();      // Draw characters of the default font

  testdrawstyles();    // Draw 'stylized' characters

  testscrolltext();    // Draw scrolling text

  testdrawbitmap();    // Draw a small bitmap image

  // Invert and restore display, pausing in-between
  display.invertDisplay(true);
  delay(1000);
  display.invertDisplay(false);
  delay(1000);

  testanimate(logo_bmp, LOGO_WIDTH, LOGO_HEIGHT); // Animate bitmaps
}

void loop() {
}

void testdrawline() {
  int16_t i;

  display.clearDisplay(); // Clear display buffer

  for(i=0; i<display.width(); i+=4) {
    display.drawLine(0, 0, i, display.height()-1, SSD1306_WHITE);
    display.display(); // Update screen with each newly-drawn line
    delay(1);
  }
  for(i=0; i<display.height(); i+=4) {
    display.drawLine(0, 0, display.width()-1, i, SSD1306_WHITE);
    display.display();
    delay(1);
  }
  delay(250);

  display.clearDisplay();

  for(i=0; i<display.width(); i+=4) {
    display.drawLine(0, display.height()-1, i, 0, SSD1306_WHITE);
    display.display();
    delay(1);
  }
  for(i=display.height()-1; i>=0; i-=4) {
    display.drawLine(0, display.height()-1, display.width()-1, i, SSD1306_WHITE);
    display.display();
    delay(1);
  }
  delay(250);

  display.clearDisplay();

  for(i=display.width()-1; i>=0; i-=4) {
    display.drawLine(display.width()-1, display.height()-1, i, 0, SSD1306_WHITE);
    display.display();
    delay(1);
  }
  for(i=display.height()-1; i>=0; i-=4) {
    display.drawLine(display.width()-1, display.height()-1, 0, i, SSD1306_WHITE);
    display.display();
    delay(1);
  }
  delay(250);

  display.clearDisplay();

  for(i=0; i<display.height(); i+=4) {
    display.drawLine(display.width()-1, 0, 0, i, SSD1306_WHITE);
    display.display();
    delay(1);
  }
  for(i=0; i<display.width(); i+=4) {
    display.drawLine(display.width()-1, 0, i, display.height()-1, SSD1306_WHITE);
    display.display();
    delay(1);
  }

  delay(2000); // Pause for 2 seconds
}

void testdrawrect(void) {
  display.clearDisplay();

  for(int16_t i=0; i<display.height()/2; i+=2) {
    display.drawRect(i, i, display.width()-2*i, display.height()-2*i, SSD1306_WHITE);
    display.display(); // Update screen with each newly-drawn rectangle
    delay(1);
  }

  delay(2000);
}

void testfillrect(void) {
  display.clearDisplay();

  for(int16_t i=0; i<display.height()/2; i+=3) {
    // The INVERSE color is used so rectangles alternate white/black
    display.fillRect(i, i, display.width()-i*2, display.height()-i*2, SSD1306_INVERSE);
    display.display(); // Update screen with each newly-drawn rectangle
    delay(1);
  }

  delay(2000);
}

void testdrawcircle(void) {
  display.clearDisplay();

  for(int16_t i=0; i<max(display.width(),display.height())/2; i+=2) {
    display.drawCircle(display.width()/2, display.height()/2, i, SSD1306_WHITE);
    display.display();
    delay(1);
  }

  delay(2000);
}

void testfillcircle(void) {
  display.clearDisplay();

  for(int16_t i=max(display.width(),display.height())/2; i>0; i-=3) {
    // The INVERSE color is used so circles alternate white/black
    display.fillCircle(display.width() / 2, display.height() / 2, i, SSD1306_INVERSE);
    display.display(); // Update screen with each newly-drawn circle
    delay(1);
  }

  delay(2000);
}

void testdrawroundrect(void) {
  display.clearDisplay();

  for(int16_t i=0; i<display.height()/2-2; i+=2) {
    display.drawRoundRect(i, i, display.width()-2*i, display.height()-2*i,
      display.height()/4, SSD1306_WHITE);
    display.display();
    delay(1);
  }

  delay(2000);
}

void testfillroundrect(void) {
  display.clearDisplay();

  for(int16_t i=0; i<display.height()/2-2; i+=2) {
    // The INVERSE color is used so round-rects alternate white/black
    display.fillRoundRect(i, i, display.width()-2*i, display.height()-2*i,
      display.height()/4, SSD1306_INVERSE);
    display.display();
    delay(1);
  }

  delay(2000);
}

void testdrawtriangle(void) {
  display.clearDisplay();

  for(int16_t i=0; i<max(display.width(),display.height())/2; i+=5) {
    display.drawTriangle(
      display.width()/2  , display.height()/2-i,
      display.width()/2-i, display.height()/2+i,
      display.width()/2+i, display.height()/2+i, SSD1306_WHITE);
    display.display();
    delay(1);
  }

  delay(2000);
}

void testfilltriangle(void) {
  display.clearDisplay();

  for(int16_t i=max(display.width(),display.height())/2; i>0; i-=5) {
    // The INVERSE color is used so triangles alternate white/black
    display.fillTriangle(
      display.width()/2  , display.height()/2-i,
      display.width()/2-i, display.height()/2+i,
      display.width()/2+i, display.height()/2+i, SSD1306_INVERSE);
    display.display();
    delay(1);
  }

  delay(2000);
}

void testdrawchar(void) {
  display.clearDisplay();

  display.setTextSize(1);      // Normal 1:1 pixel scale
  display.setTextColor(SSD1306_WHITE); // Draw white text
  display.setCursor(0, 0);     // Start at top-left corner
  display.cp437(true);         // Use full 256 char 'Code Page 437' font

  // Not all the characters will fit on the display. This is normal.
  // Library will draw what it can and the rest will be clipped.
  for(int16_t i=0; i<256; i++) {
    if(i == '\n') display.write(' ');
    else          display.write(i);
  }

  display.display();
  delay(2000);
}

void testdrawstyles(void) {
  display.clearDisplay();

  display.setTextSize(1);             // Normal 1:1 pixel scale
  display.setTextColor(SSD1306_WHITE);        // Draw white text
  display.setCursor(0,0);             // Start at top-left corner
  display.println(F("Hello, world!"));

  display.setTextColor(SSD1306_BLACK, SSD1306_WHITE); // Draw 'inverse' text
  display.println(3.141592);

  display.setTextSize(2);             // Draw 2X-scale text
  display.setTextColor(SSD1306_WHITE);
  display.print(F("0x")); display.println(0xDEADBEEF, HEX);

  display.display();
  delay(2000);
}

void testscrolltext(void) {
  display.clearDisplay();

  display.setTextSize(2); // Draw 2X-scale text
  display.setTextColor(SSD1306_WHITE);
  display.setCursor(10, 0);
  display.println(F("scroll"));
  display.display();      // Show initial text
  delay(100);

  // Scroll in various directions, pausing in-between:
  display.startscrollright(0x00, 0x0F);
  delay(2000);
  display.stopscroll();
  delay(1000);
  display.startscrollleft(0x00, 0x0F);
  delay(2000);
  display.stopscroll();
  delay(1000);
  display.startscrolldiagright(0x00, 0x07);
  delay(2000);
  display.startscrolldiagleft(0x00, 0x07);
  delay(2000);
  display.stopscroll();
  delay(1000);
}

void testdrawbitmap(void) {
  display.clearDisplay();

  display.drawBitmap(
    (display.width()  - LOGO_WIDTH ) / 2,
    (display.height() - LOGO_HEIGHT) / 2,
    logo_bmp, LOGO_WIDTH, LOGO_HEIGHT, 1);
  display.display();
  delay(1000);
}

#define XPOS   0 // Indexes into the 'icons' array in function below
#define YPOS   1
#define DELTAY 2

void testanimate(const uint8_t *bitmap, uint8_t w, uint8_t h) {
  int8_t f, icons[NUMFLAKES][3];

  // Initialize 'snowflake' positions
  for(f=0; f< NUMFLAKES; f++) {
    icons[f][XPOS]   = random(1 - LOGO_WIDTH, display.width());
    icons[f][YPOS]   = -LOGO_HEIGHT;
    icons[f][DELTAY] = random(1, 6);
    Serial.print(F("x: "));
    Serial.print(icons[f][XPOS], DEC);
    Serial.print(F(" y: "));
    Serial.print(icons[f][YPOS], DEC);
    Serial.print(F(" dy: "));
    Serial.println(icons[f][DELTAY], DEC);
  }

  for(;;) { // Loop forever...
    display.clearDisplay(); // Clear the display buffer

    // Draw each snowflake:
    for(f=0; f< NUMFLAKES; f++) {
      display.drawBitmap(icons[f][XPOS], icons[f][YPOS], bitmap, w, h, SSD1306_WHITE);
    }

    display.display(); // Show the display buffer on the screen
    delay(200);        // Pause for 1/10 second

    // Then update coordinates of each flake...
    for(f=0; f< NUMFLAKES; f++) {
      icons[f][YPOS] += icons[f][DELTAY];
      // If snowflake is off the bottom of the screen...
      if (icons[f][YPOS] >= display.height()) {
        // Reinitialize to a random position, just off the top
        icons[f][XPOS]   = random(1 - LOGO_WIDTH, display.width());
        icons[f][YPOS]   = -LOGO_HEIGHT;
        icons[f][DELTAY] = random(1, 6);
      }
    }
  }
}

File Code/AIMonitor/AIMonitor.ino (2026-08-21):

#include <Arduino.h>
#include <U8g2lib.h>

#include "fs.h"
#include "net.h"
#include "player.h"
#include "protocol.h"
#include "transport.h"
#include "webcfg.h"

#define SCL 5
#define SDA 4

// #define SCL 2
// #define SDA 0
// #define SCL 22
// #define SDA 21
U8G2_SSD1306_128X64_NONAME_F_SW_I2C u8g2(U8G2_R2, SCL, SDA, U8X8_PIN_NONE);

static void render_frame(const uint8_t* frame) {
  u8g2.drawXBMP(0, 0, 128, 64, frame);
  u8g2.sendBuffer();
}

// 待机信息屏：显示 WiFi 状态(模式)+名称 / 密码 / TCP 端口（AP 热点默认常开，屏上直接可查连接信息）。
static void draw_idle_info(bool blink) {
  char line[40];
  u8g2.clearBuffer();
  u8g2.setFont(u8g2_font_6x13_tf);

  if (blink) u8g2.drawBox(122, 2, 4, 4);  // 右上角呼吸指示点

  u8g2.drawStr(2, 12, "AIMonitor");

  // WiFi 状态（ap/sta/ap+sta）+ 名称（AP 开则热点名，否则 STA ssid）
  snprintf(line, sizeof(line), "%s %s", net_mode_str(),
           net_has_ap() ? net_ap_ssid_str() : net_ssid_str());
  u8g2.drawStr(2, 28, line);

  // AP 热点密码（空=开放热点；独立于 STA pass）
  if (net_ap_pass_str()[0]) snprintf(line, sizeof(line), "PASS %s", net_ap_pass_str());
  else strcpy(line, "PASS (open)");
  u8g2.drawStr(2, 44, line);

  snprintf(line, sizeof(line), "TCP %u  C:%d", (unsigned)net_port(), net_client_count());
  u8g2.drawStr(2, 60, line);

  u8g2.sendBuffer();
}

// 开机动画：纯程序化绘制（无文件依赖），阻塞约 1.5s。
static void boot_animation(void) {
  const unsigned long DUR_MS = 1500;
  const unsigned long STEP_MS = 16;
  unsigned long t0 = millis();
  u8g2.setFont(u8g2_font_6x13_tf);
  for (;;) {
    unsigned long t = millis() - t0;
    if (t >= DUR_MS) break;
    float p = (float)t / DUR_MS;

    u8g2.clearBuffer();

    // 顶部：状态圈收缩
    int r = 22 - (int)(p * 16);
    u8g2.drawCircle(64, 22, r > 0 ? r : 0);
    u8g2.drawPixel(64, 22);

    // 品牌字
    u8g2.drawStr(37, 42, "AIMonitor");

    // 底部进度条 + 进度端奔跑方块
    u8g2.drawFrame(8, 52, 112, 8);
    int bw = (int)(p * 110);
    u8g2.drawBox(10, 54, bw, 4);
    int rx = (10 + bw < 114) ? 10 + bw : 114;
    u8g2.drawBox(rx, 52, 4, 8);

    u8g2.sendBuffer();
    delay(STEP_MS);
  }
}

void setup(void) {
  // 扩大内核串口 RX 缓冲：渲染/写 Flash 阻塞期间不丢帧数据（默认仅 256B）
  Serial.setRxBufferSize(4096);
  Serial.begin(921600);
  fs_init();
  net_setup();
  webcfg_setup();
  player_init(render_frame, on_player_event);
  player_set_idle_info_cb(draw_idle_info);
  protocol_setup();
  u8g2.begin();
  boot_animation();
  u8g2.clearBuffer();
  u8g2.sendBuffer();
}

void loop(void) {
  transport_poll();
  net_poll();
  webcfg_poll();
  player_tick();
  protocol_tick();
}

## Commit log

2026-07-25 第一次提交
2026-07-25 新增了动画编辑器
2026-07-25 添加需求文档
2026-07-25 建立项目目录
2026-07-29 添加3d模型
    [OMG096.step]
2026-08-04 修改代码
2026-08-07 固件1.1.0 + 像素动画编辑器 + PXA分享格式 + 上位机工具集
    - 固件: LSB位序、串口防丢字节(setRxBufferSize/环形8192/收包超时)、开机/待机动画、LittleFS自动格式化
    - 编辑器: 黑白像素动画、设备直连(Web Serial 上传/流式预览)、导入预览(等比+自适应/轮廓二值化)、GIF编解码修复、PXA导入导出
    - 上位机: protocol/aimonitor/anm_builder/pxa/ai_stream + 回环测试13/13
    - 文档: DEV_CONTEXT(开发摘要) + 需求/设计/PXA格式 + README
    [AIMonitor.ino, ai_stream.py, aimonitor.py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]
2026-08-08 完善html 整理文件夹
    [OMG096.step]
2026-08-21 添加串口 TCP web网页
    [后盖.stl, 壳体.stl, 横棍.stl]
2026-08-21 同步文档：回环15/15 + RAM 73% + AP热点密码说明
